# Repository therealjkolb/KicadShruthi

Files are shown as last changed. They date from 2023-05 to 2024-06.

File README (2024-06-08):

# **About this project** 

Shruthi-1, a digital/analog hybrid MIDI monosynth.

This project is a port of the Shruthi-1 Design into Kicad for current manufacturing, as well as addressing component obsolecence within the design.

Primary goal of the project is to take the exiting Eagle based design files and move them to Kicad. The project is to build the Digital XT control board as well
as the SMR4mk-II filter board only.

Inherited files that are not to be remanufactured removed for cleanliness, but design files relevant to the Digital XT and the SMR4mk-II are being retained.

Current Modifier: Jake Kolb (therealjkolb@gmail.com).

Original developer: Emilie Gillet (emilie.o.gillet@gmail.com)

# **Firmware Changes** 
- 3-17-2024 -- Will Kolb(wfkolb@gmail.com)
    - Changed debounce settings to add stability in ui.cc
    - Determined that building with avr-gcc 4.3.3 is the **ONLY** way to have successful page navigation. (Added a comment to editor.cc to show the failure point for other compilers)
    - Updated dsp/Makefile to point to the proper mcu (644p)

# **Code/Asset Licenses** 

The firmware is (still) released under a GPL3.0 license. It includes a
reimplementation of the formant synthesis algorithm used in Peter Knight's
Cantarino speech synthesizer.

The PCB layouts and schematics (in /hardware/shruthi/design/pcb)
are released under a Creative Commons cc-by-sa 3.0 license 

SMR4_MkII_V03 Filter board and the Digital XT filter board included, both ported from the orignal design files in Eagle to Kicad 6.

Additional footprint and rounting updates made on the SMR4_MKII filter board for manufacturability.

Documentation, analyses, simulations and 3D models are released under a
Creative Commons cc-by-sa 3.0 license.

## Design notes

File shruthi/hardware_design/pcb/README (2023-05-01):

PCB art (not used on these boards as of April 2023):
- "saraswati" by Francois Barbut.
- "peacock_face" by Emilie Gillet.
- "radha" by Emilie Gillet.

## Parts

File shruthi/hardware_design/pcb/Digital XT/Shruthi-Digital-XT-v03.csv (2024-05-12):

Source: | D:\JDocuments\Projects\Electronics\Synth_clone\shruthi-1_kicad\Shruthi-Digital-XT-v03\Shruthi-Digital-XT-v03.kicad_sch
Date: | 3/15/2024 7:17:12 AM
Tool: | Eeschema (6.0.0)
Generator: | C:\Program Files\KiCad\6.0\bin\scripting\plugins/bom_csv_grouped_by_value.py
Component Count: | 118
Individual Components:
Item | Qty | Reference(s) | Value | LibPart | Footprint | Datasheet
 |  | C1 | 100n | Shruthi-Digital-XT-v03-eagle-import:C-US025-024X044 | C025-024X044
 |  | C2 | 100n | Shruthi-Digital-XT-v03-eagle-import:C-US025-024X044 | C025-024X044
 |  | C3 | 100n | Shruthi-Digital-XT-v03-eagle-import:C-US025-024X044 | C025-024X044
 |  | C4 | 100u | Shruthi-Digital-XT-v03-eagle-import:CPOL-EUE2.5-7 | E2,5-7
 |  | C5 | 100n | Shruthi-Digital-XT-v03-eagle-import:C-US025-024X044 | C025-024X044
 |  | C6 | 100n | Shruthi-Digital-XT-v03-eagle-import:C-US025-024X044 | C025-024X044
 |  | C7 | 100n | Shruthi-Digital-XT-v03-eagle-import:C-US025-024X044 | C025-024X044
 |  | C8 | 100n | Shruthi-Digital-XT-v03-eagle-import:C-US025-024X044 | C025-024X044
 |  | C9 | 100n | Shruthi-Digital-XT-v03-eagle-import:C-US025-024X044 | C025-024X044
 |  | C10 | 100n | Shruthi-Digital-XT-v03-eagle-import:C-US025-024X044 | C025-024X044
 |  | C11 | 18p | Shruthi-Digital-XT-v03-eagle-import:C-US025-024X044 | C025-024X044
 |  | C12 | 18p | Shruthi-Digital-XT-v03-eagle-import:C-US025-024X044 | C025-024X044
 |  | C13 | 100n | Shruthi-Digital-XT-v03-eagle-import:C-US025-024X044 | C025-024X044
 |  | C14 | 100n | Shruthi-Digital-XT-v03-eagle-import:C-US025-024X044 | C025-024X044
 |  | C15 | 100n | Shruthi-Digital-XT-v03-eagle-import:C-US025-024X044 | C025-024X044
 |  | C16 | 100n | Shruthi-Digital-XT-v03-eagle-import:C-US025-024X044 | C025-024X044
 |  | C17 | 100n | Shruthi-Digital-XT-v03-eagle-import:C-US025-024X044 | C025-024X044
 |  | D1 | 1N4148 | Shruthi-Digital-XT-v03-eagle-import:DIODE-D-5 | D-5
 |  | IC1 | 24LC512 | Shruthi-Digital-XT-v03-eagle-import:AT24CP | DIL08
 |  | IC2 | 74HC165N | Shruthi-Digital-XT-v03-eagle-import:74165N | DIL16
 |  | IC3 | 74HC165N | Shruthi-Digital-XT-v03-eagle-import:74165N | DIL16
 |  | IC4 | 4051N | Shruthi-Digital-XT-v03-eagle-import:4051N | DIL16
 |  | IC5 | 4051N | Shruthi-Digital-XT-v03-eagle-import:4051N | DIL16
 |  | IC6 | 4051N | Shruthi-Digital-XT-v03-eagle-import:4051N | DIL16
 |  | IC7 | 4051N | Shruthi-Digital-XT-v03-eagle-import:4051N | DIL16
 |  | IC8 | 74595N | Shruthi-Digital-XT-v03-eagle-import:74595N | DIL16
 |  | IC9 | 74HC165N | Shruthi-Digital-XT-v03-eagle-import:74165N | DIL16
 |  | IC10 | ATMEGA644p | Shruthi-Digital-XT-v03-eagle-import:MEGA16-P | DIL40
 |  | J1 | M06SIP | Shruthi-Digital-XT-v03-eagle-import:M06SIP | 1X06
 |  | J2 | POWER | Shruthi-Digital-XT-v03-eagle-import:M02PTH | 1X02
 |  | J3 | M03PTH | Shruthi-Digital-XT-v03-eagle-import:M03PTH | 1X03
 |  | J4 | POWER | Shruthi-Digital-XT-v03-eagle-import:M02PTH | 1X02
 |  | JP1 | M03PTH | Shruthi-Digital-XT-v03-eagle-import:M03PTH | 1X03
 |  | JP2 | M03PTH | Shruthi-Digital-XT-v03-eagle-import:M03PTH | 1X03
 |  | JP3 | M01PTH | Shruthi-Digital-XT-v03-eagle-import:M01PTH | 1X01
 |  | LCD1 | LCD-16X2 | Shruthi-Digital-XT-v03-eagle-import:LCD-16X2 | LCD-16X2
 |  | LED1 | LED3MM | Shruthi-Digital-XT-v03-eagle-import:LED3MM | LED3MM
 |  | LED2 | LED3MM | Shruthi-Digital-XT-v03-eagle-import:LED3MM | LED3MM
 |  | LED3 | LED3MM | Shruthi-Digital-XT-v03-eagle-import:LED3MM | LED3MM
 |  | LED4 | LED3MM | Shruthi-Digital-XT-v03-eagle-import:LED3MM | LED3MM
 |  | LED5 | LED3MM | Shruthi-Digital-XT-v03-eagle-import:LED3MM | LED3MM
 |  | LED6 | LED3MM | Shruthi-Digital-XT-v03-eagle-import:LED3MM | LED3MM
 |  | LED7 | LED3MM | Shruthi-Digital-XT-v03-eagle-import:LED3MM | LED3MM
 |  | LED8 | LED3MM | Shruthi-Digital-XT-v03-eagle-import:LED3MM | LED3MM
 |  | OK1 | 6N137 | Shruthi-Digital-XT-v03-eagle-import:6N137 | DIL08
 |  | Q1 | 20MHz | Shruthi-Digital-XT-v03-eagle-import:CRYSTALHC49U-V | HC49U-V
 |  | R1 | 5k | Shruthi-Digital-XT-v03-eagle-import:R-TRIMM3339P | RTRIM3339P
 |  | R2 | R_LCD | Shruthi-Digital-XT-v03-eagle-import:R-US_0204{slash}7 | 0204_7
 |  | R3 | 10kB | Shruthi-Digital-XT-v03-eagle-import:POT_USVERTICAL | ALPS_POT_VERTICAL
 |  | R4 | 10kB | Shruthi-Digital-XT-v03-eagle-import:POT_USVERTICAL | ALPS_POT_VERTICAL
 |  | R5 | 10kB | Shruthi-Digital-XT-v03-eagle-import:POT_USVERTICAL | ALPS_POT_VERTICAL
 |  | R6 | 10kB | Shruthi-Digital-XT-v03-eagle-import:POT_USVERTICAL | ALPS_POT_VERTICAL
 |  | R7 | 10kB | Shruthi-Digital-XT-v03-eagle-import:POT_USVERTICAL | ALPS_POT_VERTICAL
 |  | R8 | 10kB | Shruthi-Digital-XT-v03-eagle-import:POT_USVERTICAL | ALPS_POT_VERTICAL
 |  | R9 | 2.2k | Shruthi-Digital-XT-v03-eagle-import:R-US_0204{slash}7 | 0204_7
 |  | R10 | 2.2k | Shruthi-Digital-XT-v03-eagle-import:R-US_0204{slash}7 | 0204_7
 |  | R11 | 10kB | Shruthi-Digital-XT-v03-eagle-import:POT_USVERTICAL | ALPS_POT_VERTICAL
 |  | R12 | POT | Shruthi-Digital-XT-v03-eagle-import:POT_USVERTICAL | ALPS_POT_VERTICAL
 |  | R13 | 10kB | Shruthi-Digital-XT-v03-eagle-import:POT_USVERTICAL | ALPS_POT_VERTICAL
 |  | R14 | 10kB | Shruthi-Digital-XT-v03-eagle-import:POT_USVERTICAL | ALPS_POT_VERTICAL
 |  | R15 | 220 | Shruthi-Digital-XT-v03-eagle-import:R-US_0204{slash}7 | 0204_7
 |  | R16 | 220 | Shruthi-Digital-XT-v03-eagle-import:R-US_0204{slash}7 | 0204_7
 |  | R17 | 220 | Shruthi-Digital-XT-v03-eagle-import:R-US_0204{slash}7 | 0204_7
 |  | R18 | 10k | Shruthi-Digital-XT-v03-eagle-import:R-US_0204{slash}7 | 0204_7
 |  | R19 | 10k | Shruthi-Digital-XT-v03-eagle-import:R-US_0204{slash}7 | 0204_7
 |  | R20 | 10kB | Shruthi-Digital-XT-v03-eagle-import:POT_USVERTICAL | ALPS_POT_VERTICAL
 |  | R21 | 10kB | Shruthi-Digital-XT-v03-eagle-import:POT_USVERTICAL | ALPS_POT_VERTICAL
 |  | R22 | 10kB | Shruthi-Digital-XT-v03-eagle-import:POT_USVERTICAL | ALPS_POT_VERTICAL
 |  | R23 | 10kB | Shruthi-Digital-XT-v03-eagle-import:POT_USVERTICAL | ALPS_POT_VERTICAL
 |  | R24 | 10kB | Shruthi-Digital-XT-v03-eagle-import:POT_USVERTICAL | ALPS_POT_VERTICAL
 |  | R25 | 10kB | Shruthi-Digital-XT-v03-eagle-import:POT_USVERTICAL | ALPS_POT_VERTICAL
 |  | R26 | 10kB | Shruthi-Digital-XT-v03-eagle-import:POT_USVERTICAL | ALPS_POT_VERTICAL
 |  | R27 | 10kB | Shruthi-Digital-XT-v03-eagle-import:POT_USVERTICAL | ALPS_POT_VERTICAL
 |  | R28 | 10kB | Shruthi-Digital-XT-v03-eagle-import:POT_USVERTICAL | ALPS_POT_VERTICAL
 |  | R29 | 10kB | Shruthi-Digital-XT-v03-eagle-import:POT_USVERTICAL | ALPS_POT_VERTICAL
 |  | R30 | 10kB | Shruthi-Digital-XT-v03-eagle-import:POT_USVERTICAL | ALPS_POT_VERTICAL
 |  | R31 | 220 | Shruthi-Digital-XT-v03-eagle-import:R-US_0204{slash}7 | 0204_7
 |  | R32 | 220 | Shruthi-Digital-XT-v03-eagle-import:R-US_0204{slash}7 | 0204_7
 |  | R33 | 220 | Shruthi-Digital-XT-v03-eagle-import:R-US_0204{slash}7 | 0204_7
 |  | R34 | 220 | Shruthi-Digital-XT-v03-eagle-import:R-US_0204{slash}7 | 0204_7
 |  | R35 | 220 | Shruthi-Digital-XT-v03-eagle-import:R-US_0204{slash}7 | 0204_7
 |  | R36 | 220 | Shruthi-Digital-XT-v03-eagle-import:R-US_0204{slash}7 | 0204_7
 |  | R37 | 220 | Shruthi-Digital-XT-v03-eagle-import:R-US_0204{slash}7 | 0204_7
 |  | R38 | 220 | Shruthi-Digital-XT-v03-eagle-import:R-US_0204{slash}7 | 0204_7
 |  | R39 | 10kB | Shruthi-Digital-XT-v03-eagle-import:POT_USVERTICAL | ALPS_POT_VERTICAL
 |  | R40 | 10kB | Shruthi-Digital-XT-v03-eagle-import:POT_USVERTICAL | ALPS_POT_VERTICAL
 |  | R41 | 10kB | Shruthi-Digital-XT-v03-eagle-import:POT_USVERTICAL | ALPS_POT_VERTICAL
 |  | R42 | 10kB | Shruthi-Digital-XT-v03-eagle-import:POT_USVERTICAL | ALPS_POT_VERTICAL
 |  | R43 | 10kB | Shruthi-Digital-XT-v03-eagle-import:POT_USVERTICAL | ALPS_POT_VERTICAL
 |  | R44 | 10kB | Shruthi-Digital-XT-v03-eagle-import:POT_USVERTICAL | ALPS_POT_VERTICAL
 |  | R45 | 10kB | Shruthi-Digital-XT-v03-eagle-import:POT_USVERTICAL | ALPS_POT_VERTICAL
 |  | R46 | 10kB | Shruthi-Digital-XT-v03-eagle-import:POT_USVERTICAL | ALPS_POT_VERTICAL
 |  | RN1 | 10k | Shruthi-Digital-XT-v03-eagle-import:G08R | SIL9
 |  | RN2 | 10k | Shruthi-Digital-XT-v03-eagle-import:G08R | SIL9
 |  | RN3 | 10k | Shruthi-Digital-XT-v03-eagle-import:G08R | SIL9
 |  | S1 | 40-XX | Shruthi-Digital-XT-v03-eagle-import:40-XX | B3F-40XX
 |  | S2 | 40-XX | Shruthi-Digital-XT-v03-eagle-import:40-XX | B3F-40XX
 |  | S3 | 40-XX | Shruthi-Digital-XT-v03-eagle-import:40-XX | B3F-40XX
 |  | S4 | 40-XX | Shruthi-Digital-XT-v03-eagle-import:40-XX | B3F-40XX
 |  | S5 | 40-XX | Shruthi-Digital-XT-v03-eagle-import:40-XX | B3F-40XX
 |  | S6 | 40-XX | Shruthi-Digital-XT-v03-eagle-import:40-XX | B3F-40XX
 |  | S7 | 40-XX | Shruthi-Digital-XT-v03-eagle-import:40-XX | B3F-40XX
 |  | S8 | 40-XX | Shruthi-Digital-XT-v03-eagle-import:40-XX | B3F-40XX
 |  | S9 | 40-XX | Shruthi-Digital-XT-v03-eagle-import:40-XX | B3F-40XX
 |  | S10 | 40-XX | Shruthi-Digital-XT-v03-eagle-import:40-XX | B3F-40XX
 |  | S11 | 40-XX | Shruthi-Digital-XT-v03-eagle-import:40-XX | B3F-40XX
 |  | S12 | 40-XX | Shruthi-Digital-XT-v03-eagle-import:40-XX | B3F-40XX
 |  | S13 | 40-XX | Shruthi-Digital-XT-v03-eagle-import:40-XX | B3F-40XX
 |  | S14 | 40-XX | Shruthi-Digital-XT-v03-eagle-import:40-XX | B3F-40XX
 |  | S15 | 40-XX | Shruthi-Digital-XT-v03-eagle-import:40-XX | B3F-40XX
 |  | S16 | 40-XX | Shruthi-Digital-XT-v03-eagle-import:40-XX | B3F-40XX
 |  | S17 | 40-XX | Shruthi-Digital-XT-v03-eagle-import:40-XX | B3F-40XX
 |  | S18 | 40-XX | Shruthi-Digital-XT-v03-eagle-import:40-XX | B3F-40XX
 |  | S19 | 40-XX | Shruthi-Digital-XT-v03-eagle-import:40-XX | B3F-40XX
 |  | SW1 | Encoder | Shruthi-Digital-XT-v03-eagle-import:EC12E_SW | ALPS_EC12E_SW
 |  | U1 | AVRISP | Shruthi-Digital-XT-v03-eagle-import:AVR_SPI_PRG_6PTH | 2X3
 |  | X1 | MIDI | Shruthi-Digital-XT-v03-eagle-import:MAB5SH | MAB5SH
 |  | X2 | MIDI | Shruthi-Digital-XT-v03-eagle-import:MAB5SH | MAB5SH
Collated Components:
Item | Qty | Reference(s) | Value | LibPart | Footprint | Datasheet
1 | 14 | C1, C2, C3, C5, C6, C7, C8, C9, C10, C13, C14, C15, C16, C17 | 100n | Shruthi-Digital-XT-v03-eagle-import:C-US025-024X044 | C025-024X044
2 | 1 | C4 | 100u | Shruthi-Digital-XT-v03-eagle-import:CPOL-EUE2.5-7 | E2,5-7
3 | 2 | C11, C12 | 18p | Shruthi-Digital-XT-v03-eagle-import:C-US025-024X044 | C025-024X044
4 | 1 | D1 | 1N4148 | Shruthi-Digital-XT-v03-eagle-import:DIODE-D-5 | D-5
5 | 1 | IC1 | 24LC512 | Shruthi-Digital-XT-v03-eagle-import:AT24CP | DIL08
6 | 3 | IC2, IC3, IC9 | 74HC165N | Shruthi-Digital-XT-v03-eagle-import:74165N | DIL16
7 | 4 | IC4, IC5, IC6, IC7 | 4051N | Shruthi-Digital-XT-v03-eagle-import:4051N | DIL16
8 | 1 | IC8 | 74595N | Shruthi-Digital-XT-v03-eagle-import:74595N | DIL16
9 | 1 | IC10 | ATMEGA644p | Shruthi-Digital-XT-v03-eagle-import:MEGA16-P | DIL40
10 | 1 | J1 | M06SIP | Shruthi-Digital-XT-v03-eagle-import:M06SIP | 1X06
11 | 2 | J2, J4 | POWER | Shruthi-Digital-XT-v03-eagle-import:M02PTH | 1X02
12 | 3 | J3, JP1, JP2 | M03PTH | Shruthi-Digital-XT-v03-eagle-import:M03PTH | 1X03
13 | 1 | JP3 | M01PTH | Shruthi-Digital-XT-v03-eagle-import:M01PTH | 1X01
14 | 1 | LCD1 | LCD-16X2 | Shruthi-Digital-XT-v03-eagle-import:LCD-16X2 | LCD-16X2
15 | 8 | LED1, LED2, LED3, LED4, LED5, LED6, LED7, LED8 | LED3MM | Shruthi-Digital-XT-v03-eagle-import:LED3MM | LED3MM
16 | 1 | OK1 | 6N137 | Shruthi-Digital-XT-v03-eagle-import:6N137 | DIL08
17 | 1 | Q1 | 20MHz | Shruthi-Digital-XT-v03-eagle-import:CRYSTALHC49U-V | HC49U-V
18 | 1 | R1 | 5k | Shruthi-Digital-XT-v03-eagle-import:R-TRIMM3339P | RTRIM3339P
19 | 1 | R2 | R_LCD | Shruthi-Digital-XT-v03-eagle-import:R-US_0204{slash}7 | 0204_7
20 | 28 | R3, R4, R5, R6, R7, R8, R11, R13, R14, R20, R21, R22, R23, R24, R25, R26, R27, R28, R29, R30, R39, R40, R41, R42, R43, R44, R45, R46 | 10kB | Shruthi-Digital-XT-v03-eagle-import:POT_USVERTICAL | ALPS_POT_VERTICAL
21 | 2 | R9, R10 | 2.2k | Shruthi-Digital-XT-v03-eagle-import:R-US_0204{slash}7 | 0204_7
22 | 1 | R12 | POT | Shruthi-Digital-XT-v03-eagle-import:POT_USVERTICAL | ALPS_POT_VERTICAL
23 | 11 | R15, R16, R17, R31, R32, R33, R34, R35, R36, R37, R38 | 220 | Shruthi-Digital-XT-v03-eagle-import:R-US_0204{slash}7 | 0204_7
24 | 2 | R18, R19 | 10k | Shruthi-Digital-XT-v03-eagle-import:R-US_0204{slash}7 | 0204_7
25 | 3 | RN1, RN2, RN3 | 10k | Shruthi-Digital-XT-v03-eagle-import:G08R | SIL9
26 | 19 | S1, S2, S3, S4, S5, S6, S7, S8, S9, S10, S11, S12, S13, S14, S15, S16, S17, S18, S19 | 40-XX | Shruthi-Digital-XT-v03-eagle-import:40-XX | B3F-40XX
27 | 1 | SW1 | Encoder | Shruthi-Digital-XT-v03-eagle-import:EC12E_SW | ALPS_EC12E_SW
28 | 1 | U1 | AVRISP | Shruthi-Digital-XT-v03-eagle-import:AVR_SPI_PRG_6PTH | 2X3
29 | 2 | X1, X2 | MIDI | Shruthi-Digital-XT-v03-eagle-import:MAB5SH | MAB5SH

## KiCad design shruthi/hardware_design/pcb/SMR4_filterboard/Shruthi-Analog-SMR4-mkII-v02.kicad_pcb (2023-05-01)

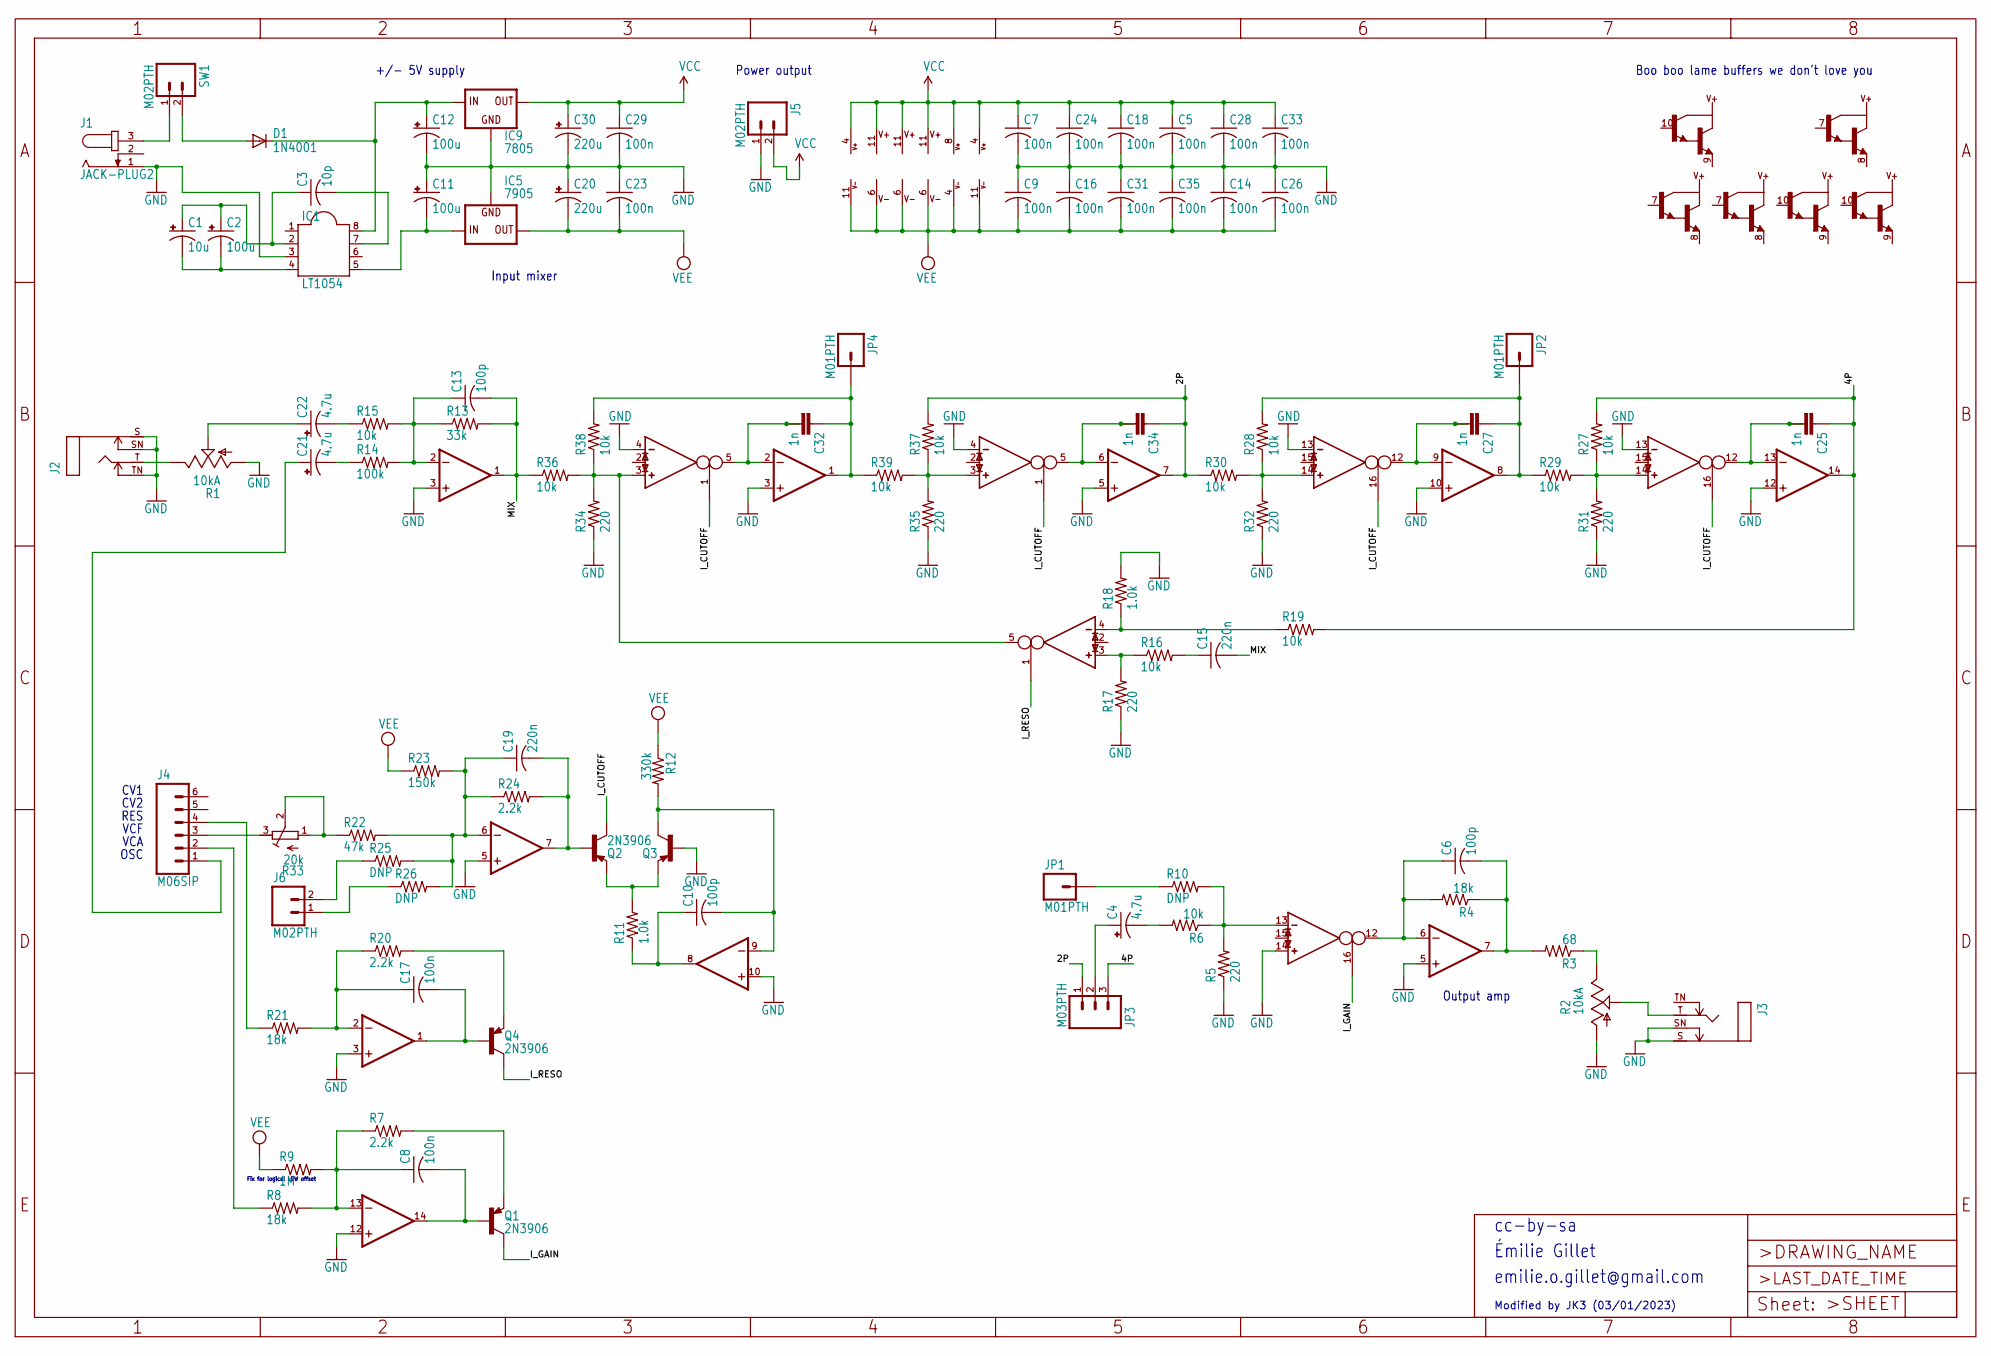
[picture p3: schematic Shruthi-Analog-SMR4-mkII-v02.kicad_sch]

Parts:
C1: 10u; E2,5-5
C2: 100u; E2,5-6
C3: 10p; C025-025X050
C4, C21, C22: 4.7u; E2,5-6
C5, C7, C8, C9, C14, C16, C17, C18, C23, C24, C26, C28, C29, C31, C33, C35: 100n; C025-025X050
C6, C10, C13: 100p; C025-025X050
C11, C12: 100u; E2,5-7
C15, C19: 220n; C025-025X050
C20, C30: 220u; E5-10,5
C25, C27, C32, C34: 1n; C2.5_5-2
D1: 1N4001; DO41-10
IC1: LT1054; DIL08
IC2: TL072P; DIL08
IC3, IC6, IC8: LM13700N; DIL16
IC4, IC7: TL074P; DIL14
IC5: 7905; 79XXS
IC9: 7805; 78XXS
J1: JACK-PLUG2; SPC4078_BIG_HOLES
J2, J3: MONOSWS; NMJ4HC-S
J4: M06SIP; 1X06
J5, J6: M02PTH; 1X02
JP1, JP2, JP4: M01PTH; 1X01
JP3: M03PTH; 1X03
Q1, Q2, Q3, Q4: 2N3906; TO92-
R1, R2: 10kA; CABLE_POT_6MM
R3: 68; 0204_7
R4, R8, R21: 18k; 0204_7
R5, R17, R31, R32, R34, R35: 220; 0204_7
R6, R15, R16, R19, R27, R28, R29, R30, R36, R37, R38, R39: 10k; 0204_7
R7, R20, R24: 2.2k; 0204_7
R9: 1M; 0204_7
R10, R25, R26: DNP; 0204V
R11, R18: 1.0k; 0204_7
R12: 330k; 0204_7
R13: 33k; 0204_7
R14: 100k; 0204_7
R22: 47k; 0204_7
R23: 150k; 0204_7
R33: 20k; RTRIM3296X
SW1: M02PTH; 1X02

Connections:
/2P: C34.1, IC7.7 (OUT), JP3.1, R30.1, R37.2
/4P: C25.1, IC7.14 (OUT), JP3.3, R19.2, R27.2
/I_CUTOFF: IC6.1 (I_BIAS), IC6.16 (I_BIAS), IC8.1 (I_BIAS), IC8.16 (I_BIAS), Q2.1 (C)
/I_GAIN: IC3.16 (I_BIAS), Q1.1 (C)
/I_RESO: IC3.1 (I_BIAS), Q4.1 (C)
/MIX: C13.2, C15.2, IC2.1 (OUT), R13.2, R36.1
GND: C5.2, C7.2, C9.1, C11.+, C12.-, C14.1, C16.1, C18.2, C20.+, C23.1, C24.2, C26.1, C28.2, C29.2, C30.-, C31.1, C33.2, C35.1, IC1.3, IC2.3 (+IN), IC2.5 (+IN), IC3.14 (IN_P), IC4.3 (+IN), IC4.5 (+IN), IC4.10 (+IN), IC4.12 (+IN), IC5.GND, IC6.4 (IN_N), IC6.13 (IN_N), IC7.3 (+IN), IC7.5 (+IN), IC7.10 (+IN), IC7.12 (+IN), IC8.4 (IN_N), IC8.13 (IN_N), IC9.GND, J1.1, J2.S, J2.SN, J2.TN, J3.S, J3.SN, J5.1, Q3.2 (B), R1.A, R2.A, R5.1, R17.1, R18.2, R31.1, R32.1, R34.1, R35.1
unnamed: C1.+, C2.+, C3.1, IC1.2
unnamed: C1.-, C2.-, IC1.4
unnamed: C3.2, IC1.7
unnamed: C4.+, JP3.2
unnamed: C4.-, R6.2
unnamed: C6.1, IC2.6 (-IN), IC3.12 (OUT), R4.2
unnamed: C6.2, IC2.7 (OUT), R3.2, R4.1
unnamed: C8.1, IC4.13 (-IN), R7.1, R8.2, R9.2
unnamed: C8.2, IC4.14 (OUT), Q1.2 (B)
unnamed: C10.1, IC4.8 (OUT), R11.1
unnamed: C10.2, IC4.9 (-IN), Q3.1 (C), R12.2
unnamed: C11.-, IC1.5, IC5.IN
unnamed: C12.+, D1.C, IC1.8, IC9.IN
unnamed: C13.1, IC2.2 (-IN), R13.1, R14.2, R15.2
unnamed: C15.1, R16.2
unnamed: C17.1, IC4.2 (-IN), R20.1, R21.2
unnamed: C17.2, IC4.1 (OUT), Q4.2 (B)
unnamed: C19.1, IC4.6 (-IN), R22.2, R23.2, R24.1, R25.2, R26.2
unnamed: C19.2, IC4.7 (OUT), Q2.2 (B), R24.2
unnamed: C21.+, J4.1
unnamed: C21.-, R14.1
unnamed: C22.+, R1.S
unnamed: C22.-, R15.1
unnamed: C25.2, C25.3, IC6.12 (OUT), IC7.13 (-IN)
unnamed: C27.1, IC7.8 (OUT), JP2.1, R28.2, R29.1
unnamed: C27.2, C27.3, IC7.9 (-IN), IC8.12 (OUT)
unnamed: C32.1, IC7.1 (OUT), JP4.1, R38.2, R39.1
unnamed: C32.2, C32.3, IC6.5 (OUT), IC7.2 (-IN)
unnamed: C34.2, C34.3, IC7.6 (-IN), IC8.5 (OUT)
unnamed: D1.A, SW1.2
unnamed: IC3.3 (IN_P), R16.1, R17.2
unnamed: IC3.4 (IN_N), R18.1, R19.1
unnamed: IC3.5 (OUT), IC6.3 (IN_P), R34.2, R36.2, R38.1
unnamed: IC3.13 (IN_N), R5.2, R6.1, R10.2
unnamed: IC6.14 (IN_P), R27.1, R29.2, R31.2
unnamed: IC8.3 (IN_P), R35.2, R37.1, R39.2
unnamed: IC8.14 (IN_P), R28.1, R30.2, R32.2
unnamed: J1.3, SW1.1
unnamed: J2.T, R1.E
unnamed: J3.T, R2.S
unnamed: J4.2, R8.1
unnamed: J4.3, R33.3 (A)
unnamed: J4.4, R21.1
unnamed: J6.1, R26.1
unnamed: J6.2, R25.1
unnamed: JP1.1, R10.1
unnamed: Q1.3 (E), R7.2
unnamed: Q2.3 (E), Q3.3 (E), R11.2
unnamed: Q4.3 (E), R20.2
unnamed: R2.E, R3.1
unnamed: R22.1, R33.1 (E), R33.2 (S)
VCC: C5.1, C7.1, C18.1, C24.1, C28.1, C29.1, C30.+, C33.1, IC2.8 (V+), IC3.11 (V+), IC4.4 (V+), IC6.11 (V+), IC7.4 (V+), IC8.11 (V+), IC9.OUT, J5.2
VEE: C9.2, C14.2, C16.2, C20.-, C23.2, C26.2, C31.2, C35.2, IC2.4 (V-), IC3.6 (V-), IC4.11 (V-), IC5.OUT, IC6.6 (V-), IC7.11 (V-), IC8.6 (V-), R9.1, R12.1, R23.1

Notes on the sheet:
OSC
Boo boo lame buffers we don't love you
Fix for logical LOW offset
cc-by-sa
+/- 5V supply
Modified by JK3 (03/01/2023)
Power output
Output amp
Input mixer
CV1
Émilie Gillet
emilie.o.gillet@gmail.com
RES
VCF
CV2
VCA

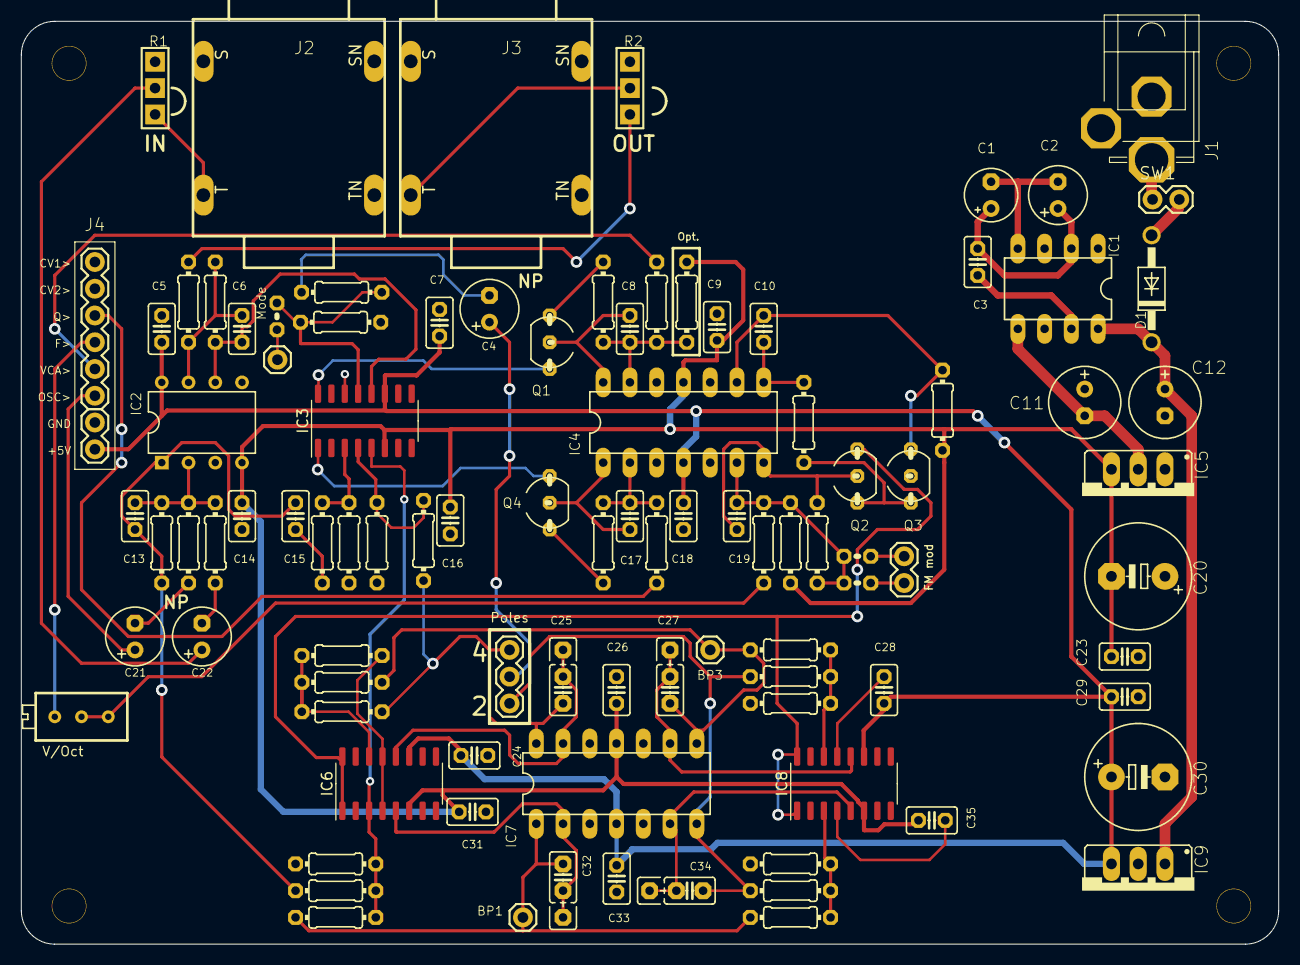
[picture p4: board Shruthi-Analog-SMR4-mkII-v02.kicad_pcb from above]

Board: 2 copper layers, 119.4 x 87.6 mm, 99 parts (0 on the bottom side), 60 nets.

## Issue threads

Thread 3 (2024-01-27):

VCF PWM Signal Does not respond to potentiometer control

therealjkolb, 2024-01-27:

therealjkolb, 2024-06-08:
Resolved with the last PR.

Closed 2024-06-08.

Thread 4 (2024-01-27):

RES Digital Control Shows no activity

therealjkolb, 2024-01-27:
When actuating the pot for Resonance of the filter. No response comes from the designated RES PWM control.

therealjkolb, 2024-06-08:
Resolved with the last PR.

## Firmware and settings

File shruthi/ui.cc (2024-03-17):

// Copyright 2013 Emilie Gillet.
//
// Author: Emilie Gillet (emilie.o.gillet@gmail.com)
//
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
// -----------------------------------------------------------------------------
//
// User interface handler.

#include "shruthi/ui.h"

#include "shruthi/editor.h"
#include "shruthi/part.h"

namespace shruthi {

using namespace avrlib;

/* static */
bool Ui::inhibit_shift_release_;
bool Ui::inhibit_encoder_release_;
uint8_t Ui::switch_state_[SWITCH_LAST];
uint32_t Ui::switch_delay_[SWITCH_LAST];
uint8_t Ui::sub_clock_;
uint8_t Ui::sub_clock_2_;
uint8_t Ui::progress_bar_;
uint8_t Ui::led_pattern_;
uint8_t Ui::led_pwm_counter_;
uint8_t Ui::pots_multiplexer_address_;
int16_t Ui::adc_values_[36];
int8_t Ui::adc_thresholds_[36];
uint8_t Ui::adc_warm_up_cycles_;
uint8_t Ui::adc_hot_address_;
uint8_t Ui::adc_resume_scan_to_;
uint32_t Ui::idle_time_;
bool Ui::freeze_display_;
Adc Ui::adc_;
EventQueue<> Ui::queue_;
SpiMaster<IOEnableLine, MSB_FIRST, 4> Ui::io_;
SpiMaster<IOEnableLineAux, MSB_FIRST, 4> Ui::aux_io_;
RotaryEncoder<EncoderALine, EncoderBLine, EncoderClickLine> Ui::encoder_;

static const int16_t kAdcThresholdLocked = 64;
static const int16_t kAdcThresholdUnlocked = 16;

/* static */
void Ui::Init() {
  io_.Init();
  aux_io_.Init();
  encoder_.Init();

  lcd.Init();
  display.Init();
  lcd.SetCustomCharMapRes(character_table[0], 7, 1);

  editor.Init();
  queue_.Flush();

  progress_bar_ = 0;
  pots_multiplexer_address_ = 0;

  inhibit_shift_release_ = false;
  memset(switch_state_, 0xff, sizeof(switch_state_));
  
  adc_.Init();
  adc_.set_reference(ADC_DEFAULT);
  adc_.set_alignment(ADC_RIGHT_ALIGNED);
  adc_.StartConversion(0);
  pots_multiplexer_address_ = 0;
    
  for (uint8_t i = 0; i < 36; ++i) {
    adc_values_[i] = -1;
    adc_thresholds_[i] = kAdcThresholdUnlocked;
  }
  adc_warm_up_cycles_ = 8;
  adc_hot_address_ = 0;
  adc_resume_scan_to_ = 0;
}

/* static */
void Ui::ShowSplash() {
  if (!encoder_.immediate_value()) {
    SystemSettings* settings = part.mutable_system_settings();
    settings->programmer = settings->programmer + 1;
    if (settings->programmer > PROGRAMMER_XT) {
      settings->programmer = 0;
    }
    settings->EepromSave();
    editor.DisplaySplashScreen(
        STR_RES_SHRUTHI_CLASSIC + (settings->programmer << 1));
    freeze_display_ = true;
  } else if (part.system_settings().start_page == START_PAGE_SPLASH) {
    editor.DisplaySplashScreen(STR_RES_V + 1);
  } else if (part.system_settings().start_page == START_PAGE_LAST_PATCH) {
    editor.BootOnPatchBrowsePage(part.system_settings().last_patch);
  } else {
    editor.Refresh();
  }
}

/* static */
void Ui::LockPotentiometers() {
  uint8_t programmer = part.system_settings().programmer;
  adc_thresholds_[0] = kAdcThresholdLocked;
  adc_thresholds_[1] = kAdcThresholdLocked;
  adc_thresholds_[2] = kAdcThresholdLocked;
  adc_thresholds_[3] = kAdcThresholdLocked;
}

const prog_uint8_t xt_parameter_mapping[] PROGMEM = {
  4 + 29,  // PRM_LFO_ATTACK_2
  4 + 30,  // PRM_LFO_RATE_2
  4 + 26,  // PRM_LFO_RATE_1
  4 + 25,  // PRM_LFO_ATTACK_1
  4 + 20,  // PRM_ENV_ATTACK_2
  4 + 23,  // PRM_ENV_RELEASE_2
  4 + 21,  // PRM_ENV_DECAY_2
  4 + 22,  // PRM_ENV_SUSTAIN_2
  
  4 + 18,  // PRM_ENV_SUSTAIN_1
  4 + 17,  // PRM_ENV_DECAY_1
  4 + 31,  // SOFTWARE VOLUME
  4 + 19,  // PRM_ENV_RELEASE_1
  4 + 16,  // PRM_ENV_ATTACK_1
  0xff,  // Unassigned
  0xff,  // Unassigned
  0xff,  // Unassigned
  
  4 + 6,  // PRM_OSC_RANGE_2
  4 + 1,  // PRM_OSC_PARAMETER_1
  4 + 5,  // PRM_OSC_PARAMETER_2
  4 + 2,  // PRM_OSC_RANGE_1
  4 + 7,  // PRM_OSC_OPTION_2
  4 + 10, // PRM_MIX_SUB_OSC
  4 + 9,  // PRM_MIX_BALANCE
  4 + 11, // PRM_MIX_NOISE
  
  0,
  1,
  2,
  3,
  4 + 12,  // PRM_FILTER_CUTOFF
  4 + 13,  // PRM_FILTER_RESONANCE
  4 + 14,  // PRM_FILTER_ENV
  4 + 15,  // PRM_FILTER_LFO
};

/* static */
void Ui::ScanPotentiometers() {
  adc_.Wait();
  uint8_t address = pots_multiplexer_address_;
  uint8_t physical_address = address;
  int16_t value = adc_.ReadOut();
  
  if (part.system_settings().programmer == PROGRAMMER_NONE) {
    *PortA::Mode::ptr() = 0x00;
    pots_multiplexer_address_ = (pots_multiplexer_address_ + 1) & 7;
    if (adc_resume_scan_to_ == 0) {
      adc_resume_scan_to_ = pots_multiplexer_address_ + 1;
      pots_multiplexer_address_ = adc_hot_address_;
    } else {
      pots_multiplexer_address_ = adc_resume_scan_to_ - 1;
      adc_resume_scan_to_ = 0;
    }    
    adc_.StartConversion(pots_multiplexer_address_);
    if (address >= 4) {
      part.mutable_voice()->set_modulation_source(
          MOD_SRC_CV_1 + address - 4, value >> 2);
      address = 0xff;
    }
  } else if (part.system_settings().programmer == PROGRAMMER_FCD) {
    *PortA::Mode::ptr() = 0x00;
    pots_multiplexer_address_++;
    if (pots_multiplexer_address_ >= 36) {
      pots_multiplexer_address_ = 0;
    }
    if (pots_multiplexer_address_ < 4) {
      adc_.StartConversion(pots_multiplexer_address_);
    } else {
      WriteShiftRegister();
      adc_.StartConversion(4);
    }
  } else if (part.system_settings().programmer == PROGRAMMER_XT) {
    *PortA::Mode::ptr() = 0xfe;
    pots_multiplexer_address_ = (pots_multiplexer_address_ + 1) & 31;
    if (adc_resume_scan_to_ == 0) {
      adc_resume_scan_to_ = pots_multiplexer_address_ + 1;
      pots_multiplexer_address_ = adc_hot_address_;
    } else {
      pots_multiplexer_address_ = adc_resume_scan_to_ - 1;
      adc_resume_scan_to_ = 0;
    }    
    uint8_t byte = (pots_multiplexer_address_ << 1) & 0x0f;
    uint8_t range = pots_multiplexer_address_ >> 3;
    byte |= (~(0x10 << range)) & 0xf0;
    *PortA::Output::ptr() = byte;
    adc_.StartConversion(0);
    address = pgm_read_byte(xt_parameter_mapping + address);
  }
  
  if (address != 0xff) {
    if (adc_warm_up_cycles_) {
      // Register the value and move on.
      adc_values_[address] = value;
      if (address == 0) {
        --adc_warm_up_cycles_;
        if (adc_warm_up_cycles_ == 0) {
          // Send a message for the volume knob
          if (part.system_settings().programmer == PROGRAMMER_XT) {
            queue_.AddEvent(CONTROL_POT, 35, adc_values_[35]);
          }
        }
      }
    } else {
      int16_t previous_value = adc_values_[address];
      int16_t delta = value - previous_value;
      int16_t threshold = adc_thresholds_[address];
      if (delta > threshold || delta < -threshold) {
        adc_hot_address_ = physical_address;
        adc_thresholds_[address] = kAdcThresholdUnlocked;
        queue_.AddEvent(CONTROL_POT, address, value >> 3);
        adc_values_[address] = value;
      }
    }
  }
}
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

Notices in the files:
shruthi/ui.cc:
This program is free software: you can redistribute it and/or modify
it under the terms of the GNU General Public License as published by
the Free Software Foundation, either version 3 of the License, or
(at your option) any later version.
